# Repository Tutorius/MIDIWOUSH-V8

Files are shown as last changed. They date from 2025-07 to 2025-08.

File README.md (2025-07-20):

# MIDIWOUSH-V8
USB-MIDI-CV-Interface with 8 outputs

All Files for the USB-MIDI-CV-Interface with 8 Outputs

a.) Software & Hardware
Files for ARDUINO IDE. Used Hardware ESP32-S3-WROOM (AliExpress), TCA9548A, GY-MCP4728, 1,30"" IIC Display (all AliExpress)
4 push-buttons (AliExpress)

b.) PCB
KiCAD-Files

To Do:

c.) PCB-Production
PCBWay-Link to project

e.) 3D-files
Files for frontplate, mounting-things, casing for use out of modular System

More Info about use and problems:

At the time i did not find a way to alter the "Midi-Name" (Its something like "ESP32S3_DEV MIDI 1"). Would be nice if it can be named "MIDIWOUSH-V8". Will try to get a solution for this.

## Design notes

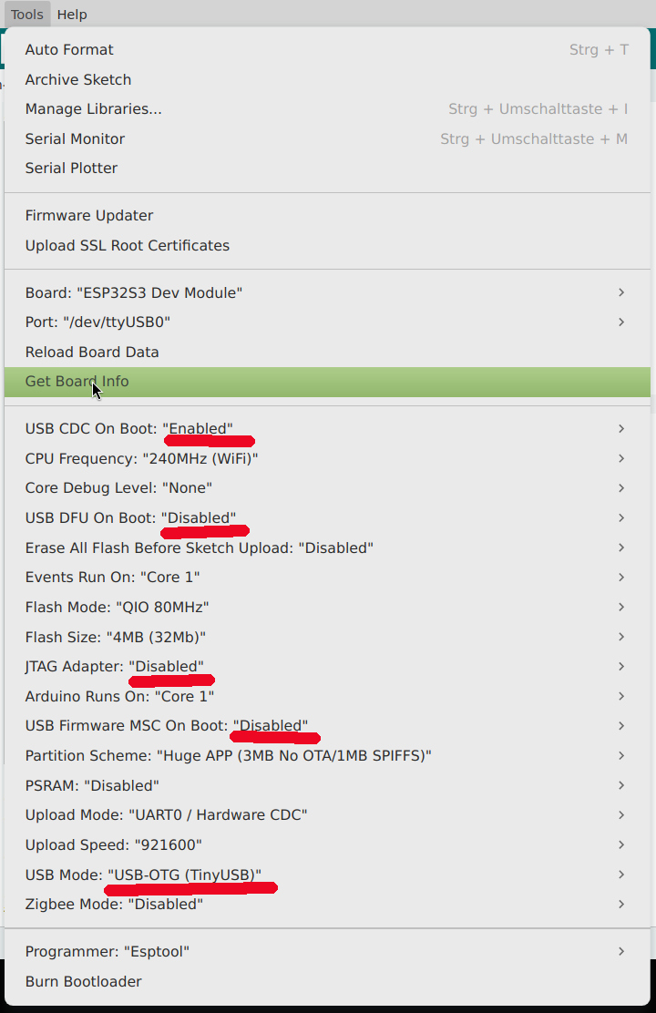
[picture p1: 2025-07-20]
Bildschirmfoto zu 2025-07-20 22-23-47.jpg

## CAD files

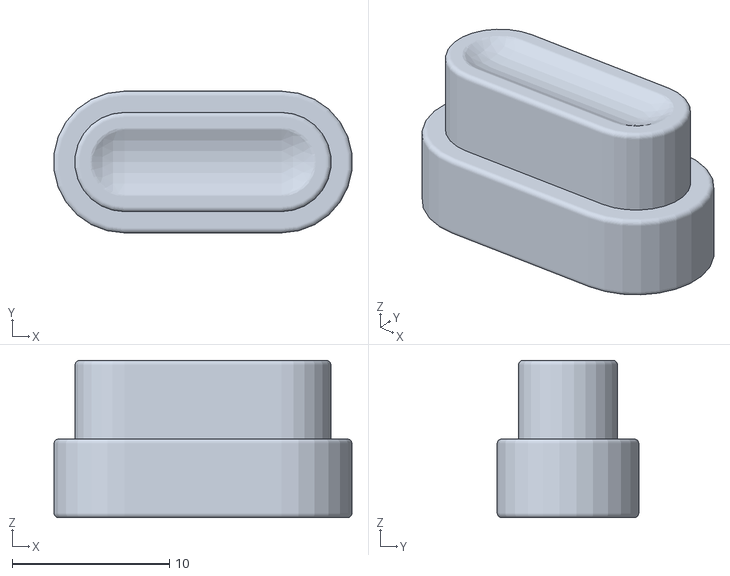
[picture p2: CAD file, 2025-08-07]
Frontplatte2-20250717-Knopf5mm.stl
18.9 x 9.00 x 10.0

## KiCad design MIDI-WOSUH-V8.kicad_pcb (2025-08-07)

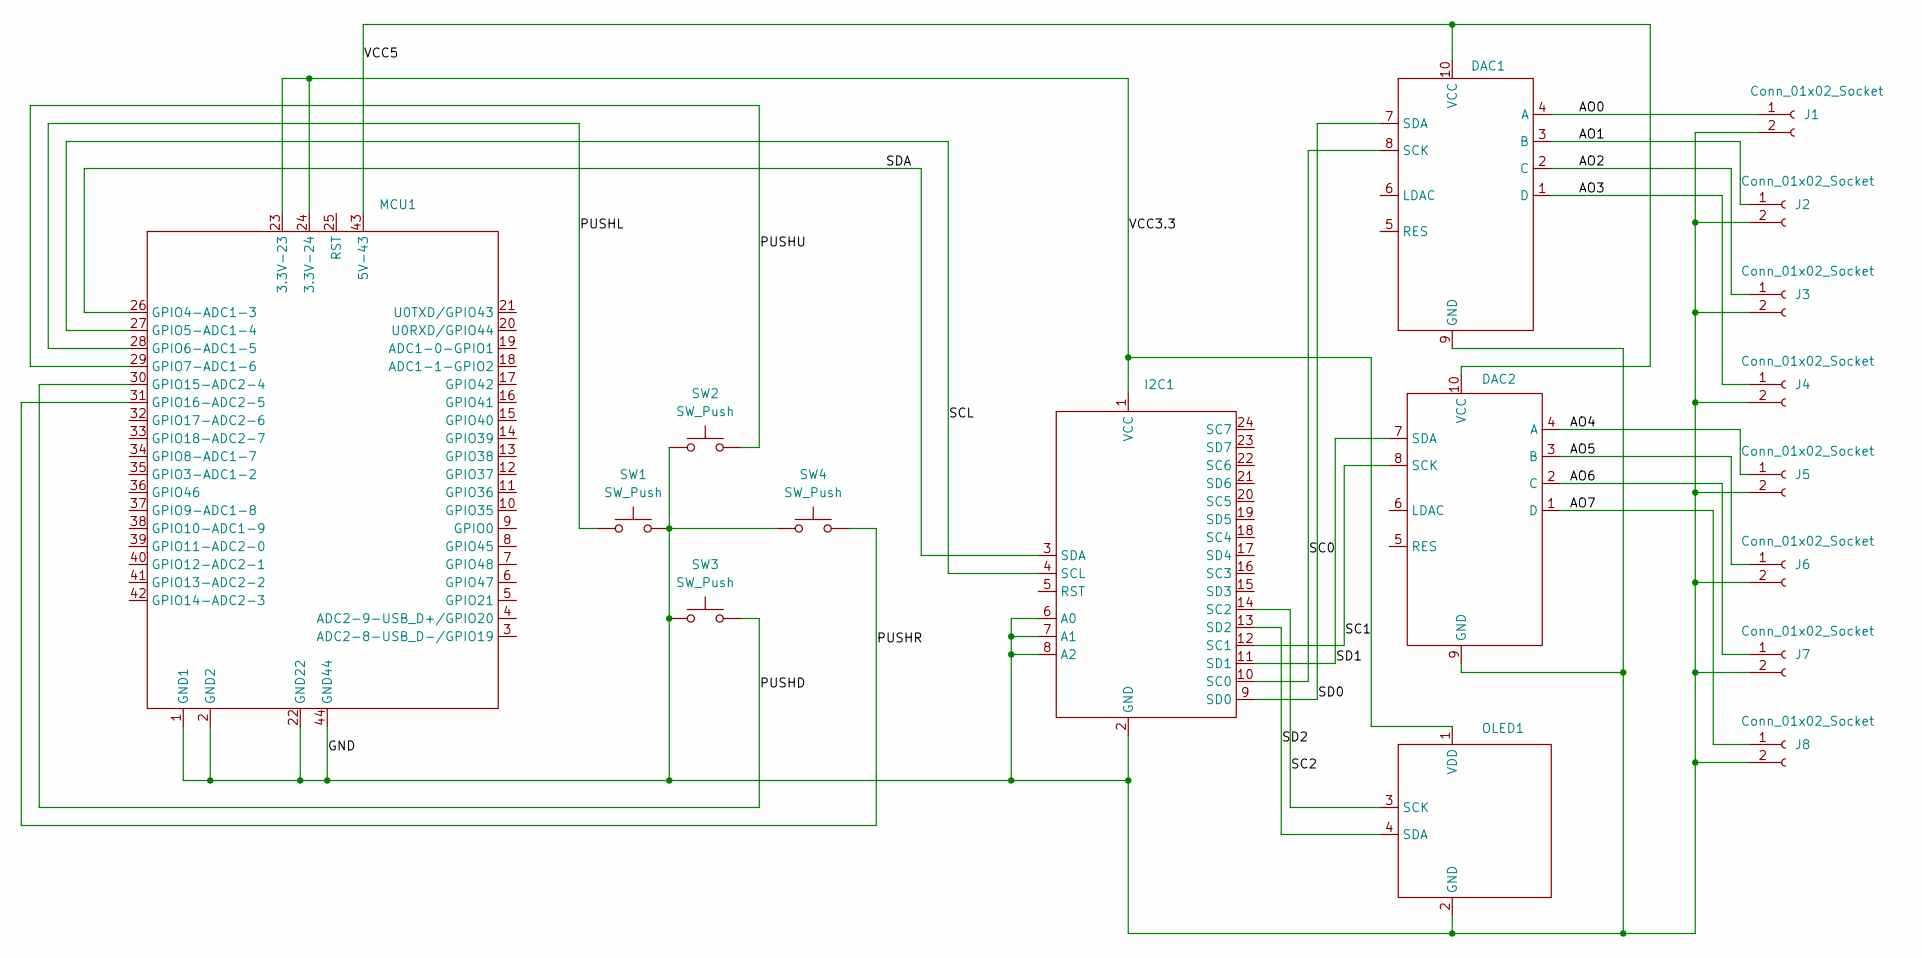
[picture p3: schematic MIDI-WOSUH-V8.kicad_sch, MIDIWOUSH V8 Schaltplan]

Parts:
DAC1, DAC2: MCP4728
I2C1: TCA9548A
J1, J2, J3, J4, J5, J6, J7, J8: Conn_01x02_Socket; PinSocket_1x02_P2.54mm_Vertical
MCU1: ESP32-S3-DevKitC-1
OLED1: OLED
SW1, SW2, SW3, SW4: SW_Push; SWITCH1

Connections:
/AO0: DAC1.4 (A), J1.1
/AO1: DAC1.3 (B), J2.1
/AO2: DAC1.2 (C), J3.1
/AO3: DAC1.1 (D), J4.1
/AO4: DAC2.4 (A), J5.1
/AO5: DAC2.3 (B), J6.1
/AO6: DAC2.2 (C), J7.1
/AO7: DAC2.1 (D), J8.1
/GND: DAC1.9 (GND), DAC2.9 (GND), I2C1.2 (GND), I2C1.6 (A0), I2C1.7 (A1), I2C1.8 (A2), J1.2, J2.2, J3.2, J4.2, J5.2, J6.2, J7.2, J8.2, MCU1.1 (GND1), MCU1.2 (GND2), MCU1.22 (GND22), MCU1.44 (GND44), OLED1.2 (GND), SW1.2, SW2.1, SW3.1, SW4.1
/PUSHD: MCU1.30 (GPIO15-ADC2-4), SW3.2
/PUSHL: MCU1.28 (GPIO6-ADC1-5), SW1.1
/PUSHR: MCU1.31 (GPIO16-ADC2-5), SW4.2
/PUSHU: MCU1.29 (GPIO7-ADC1-6), SW2.2
/SC0: DAC1.8 (SCK), I2C1.10 (SC0)
/SC1: DAC2.8 (SCK), I2C1.12 (SC1)
/SC2: I2C1.14 (SC2), OLED1.3 (SCK)
/SCL: I2C1.4 (SCL), MCU1.27 (GPIO5-ADC1-4)
/SD0: DAC1.7 (SDA), I2C1.9 (SD0)
/SD1: DAC2.7 (SDA), I2C1.11 (SD1)
/SD2: I2C1.13 (SD2), OLED1.4 (SDA)
/SDA: I2C1.3 (SDA), MCU1.26 (GPIO4-ADC1-3)
/VCC3.3: I2C1.1 (VCC), MCU1.23 (3.3V-23), MCU1.24 (3.3V-24), OLED1.1 (VDD)
/VCC5: DAC1.10 (VCC), DAC2.10 (VCC), MCU1.43 (5V-43)

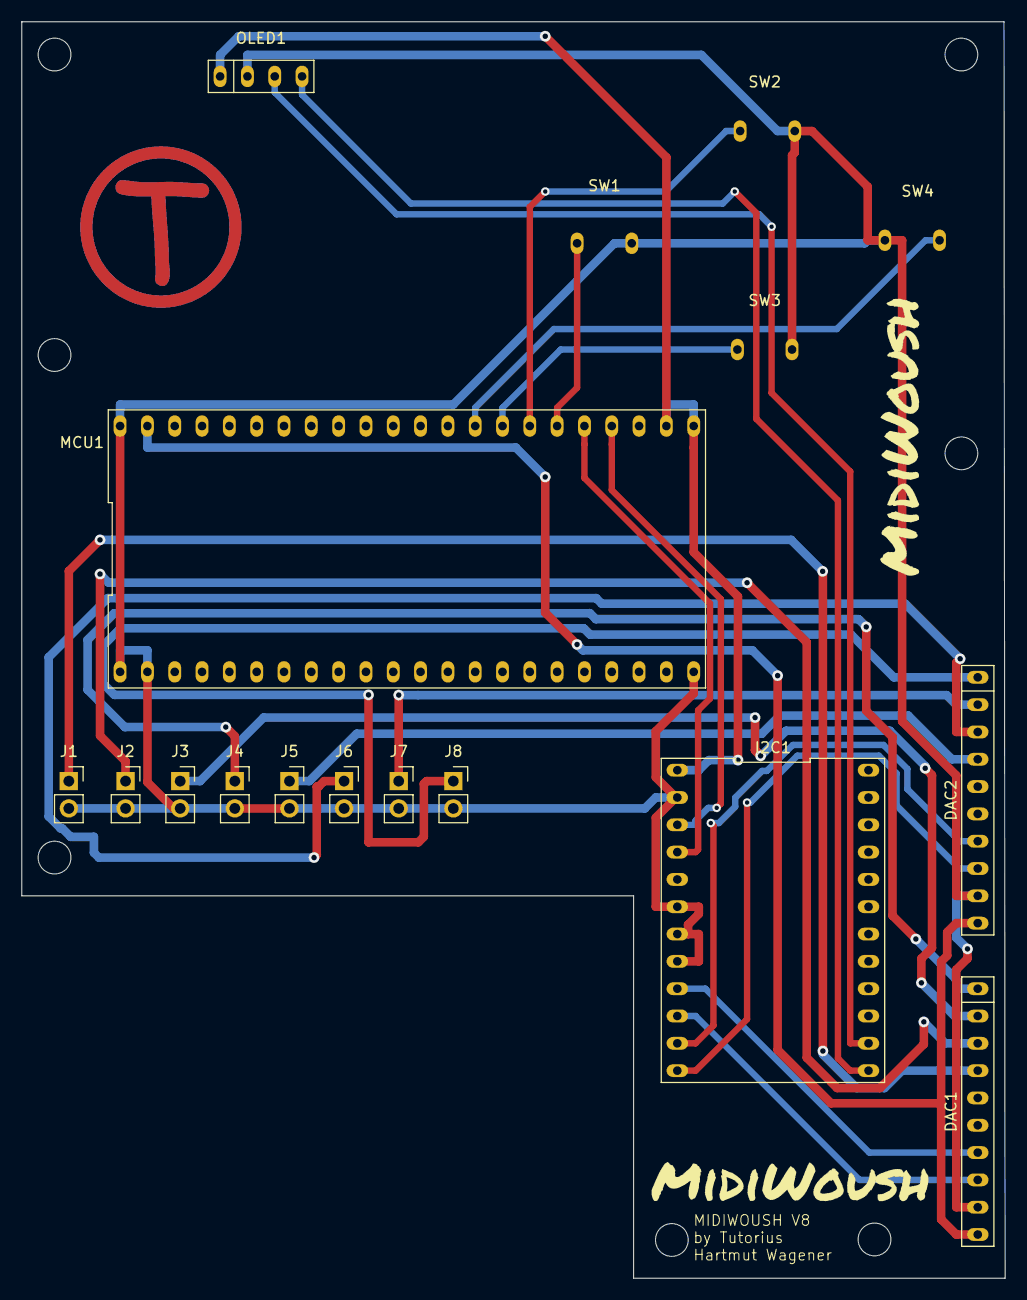
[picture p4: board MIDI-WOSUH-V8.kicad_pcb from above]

Board: 2 copper layers, 91.4 x 116.8 mm, 17 parts (0 on the bottom side), 23 nets.

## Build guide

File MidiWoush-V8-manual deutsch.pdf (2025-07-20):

V8

8-kanal MIDI-CV-Gerät mit USB-MIDI-Schnittstelle und OLED-Display

MidiWoush V8 ist ein Gerät, welches einen oder mehrere Synthesizer mit bis zu acht unabhängigen Spannungen steuern kann. Jede dieser Spannung kann auf einen beliebigen Controller und Midi-Kanal gelegt werden. Die Minimum- und Maximum-Werte können per Prozent-Wert eingegrenzt werden. Die Ausgabe kann durch Vertauschen des Minimum und Maximum-Wertes invertiert werden.
Für Informations-Anzeige und Bedienung ist das Gerät mit einem 1,3-Zoll OLED-Display ausgestattet. Während des Startvorgangs kann dieser auf dem Display verfolgt werden.

Bild 1 : Nach dem Einschalten

Wenn das System gestartet ist wird der Standard-Bildschirm angezeigt. Hier sieht man auch die Funktionen, die linke und rechte Taste durch langes drücken auslösen.

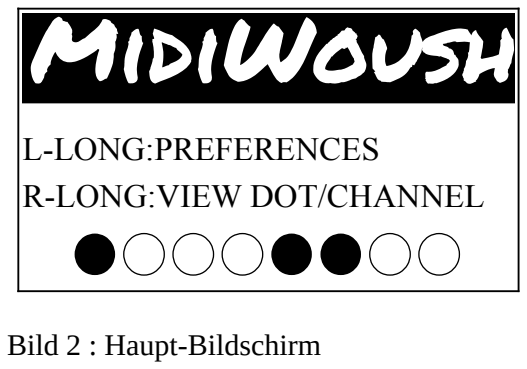
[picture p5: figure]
Bild 2 : Haupt-Bildschirm; L-LONG:PREFERENCES R-LONG:VIEW DOT/CHANNEL

Die acht Kreise zeigen die Port-Aktivität. Sind Kreise ausgefüllt, so wird auf diesem Port die Spannung geändert.

Um zur Kanal-Ansicht zu wechseln drückt man die rechte Taste für ca. eine halbe Sekunde.

INIT UNIT
MCP1
MCP2
RGB-LED

Bild 3 : Kanal-Anzeige

Jeder Kanal wird durch einen Balken angezeigt, am unteren Rand liegt 0 Volt, am oberen Rand +5 Volt.

Einstellungen ändern

Durch Drücken der linken Taste für ca. eine halbe Sekunde gelangt man ins Einstellung-Menü. Ist das Einstellungs-Menü aktiv werden keine Midi-Befehle verarbeitet, Ausgangs-Spannungen werden nicht verändert. Beendet man die Einstellung, so arbeitet MidiWoush V8 weiter wie gewünscht mit geänderten Parametern.

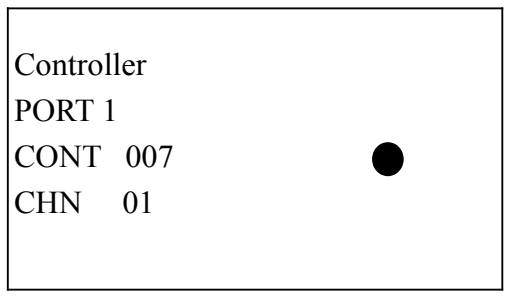
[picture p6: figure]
Controller PORT 1 CONT 007 CHN 01

Bild 4 : Einstellungs-Menü 1. Seite

Hier kann man Änderungen für alle acht Ports vornehmen. Mit dem rechten Knopf gelangt man zum nächsten Port, mit der linken Taste zum vorherigen Port. Ist man auf Port 1, so gelangt man durch die Linke Taste auf Port 8, auf Port 8 gelangt man durch die rechte Taste zu Port 1.

Der gefüllte Kreis zeigt welcher Wert durch die Hoch bzw. Runter-Taste geändert wird. Kurze Tastendrücke mit einer Pause erhöhen bzw. erniedrigen den Wert. Drückt man die Hoch oder Runter-Taste schnell hintereinander, so wird der Controller um 10 Werte erhöht oder erniedrigt, beim Midi-Kanal springt man um drei Werte.

Drückt man die Runter-Taste ca. eine halbe Sekunde, so wird der gefüllte Kreis auf die Zeile für den Midi-Kanal geschoben. Ein langer Druck auf die Hoch-Taste verschiebt diesen Kreis auf die Controller-Zeile.

Zu jeder Zeit kann man mit der linken und rechten-Taste zwischen den Ports wechseln, um schnell Parameter anpassen zu können.

Mehrfach-Belegungen Controller/Midi-Kanal

Wenn einer oder mehrere Ports die selbe Controller/Kanal-Kombination nutzen wird der Bildschirm invertiert angezeigt. Dies warnt sie, aber es funktioniert. Es ist nur keine üblicherweise gewünschte Konfiguration.

Lernen-Modus

Wenn Sie unsicher sind, welchen Controller ihre Hardware oder ihre Midi-Spur nutzt, können Sie den Lernen-Modus nutzen. Um in dden lernen-Modus zu gelangen drückt man die rechte Taste für

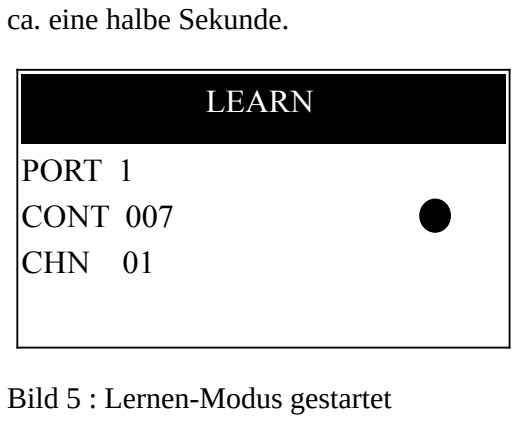
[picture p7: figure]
ca. eine halbe Sekunde.; Bild 5 : Lernen-Modus gestartet; LEARN; PORT 1 CONT 007 CHN 01

Der Text „LEARN“ wird invertiert am oberen Bildschirmrand angezeigt. Nun kann man an der Hardware den passenden Knopf bewegen oder die gewünschte Spur abspielen. Der korrekte Midi-Kanal der Hardware oder Software muss mit MidiWoush verbunden sein.

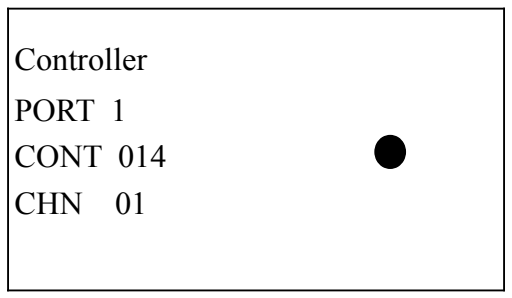
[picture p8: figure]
Controller PORT 1 CONT 014 CHN 01

Bild 6 : Nach dem Lernen

MidiWoush V8 lauscht auf dem Midi-Kanal und ändert den Kanal auf den, auf dem etwas gesendet wird. Wenn das Lernen nicht klappt oder man das unbeabsichtigt gestartet hat kann man mit der linken oder rechten Taste den Lern-Modus beenden.

Drückt man in diesem Edit-Bildschirm die linke Taste für ca. eine halbe Sekunde gelangt man zum MiniMax-Menü. Die Werte für Minimum und Maximum können durch die Hoch- und Runter-Taste geändert werden, der gefüllte Kreis kann auch hier durch langes Drücken der Hoch- und Runtertaste bewegt werden.

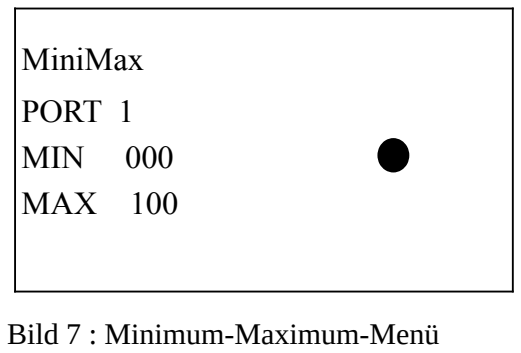
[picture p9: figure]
Bild 7 : Minimum-Maximum-Menü; MiniMax PORT 1 MIN 000 MAX 100

Ein Druck von ca. einer halben Sekunde auf den rechten Knopf vertauscht den Minimum- mit dem Maximum-Wert. Wenn das Minimum größer als das Maximum ist wird der Bildschirm invertiert angezeigt. In diesem Falle wird der Spannungswert invertiert zum Midi-Eingang ausgegeben.

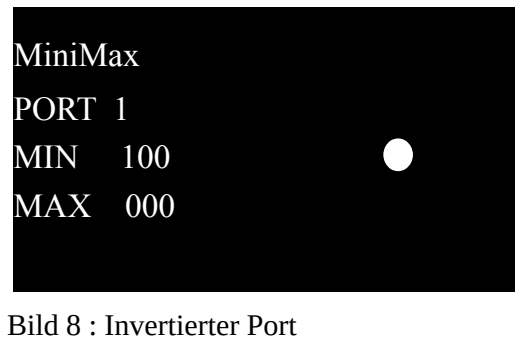
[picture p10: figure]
Bild 8 : Invertierter Port; MiniMax PORT 1 MIN 100 MAX 000

Durch Drücken der linken Taste für ca. eine halbe Sekunde werden die Einstellungen verlassen. Es wird wieder der Standard-Bildschirm angezeigt, die Midi-Kommandos werden verarbeitet,

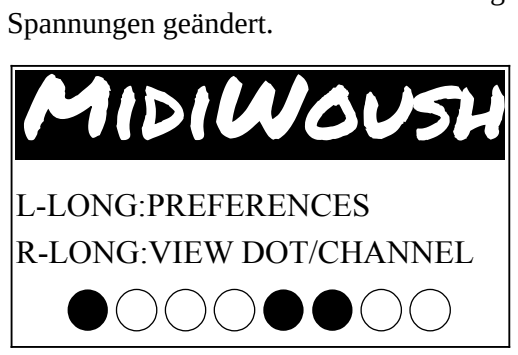
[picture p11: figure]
Spannungen geändert.; L-LONG:PREFERENCES R-LONG:VIEW DOT/CHANNEL

Bild 9 : Standard-Bildschirm wird wieder angezeigt

Werte und Neustart

Alle Änderungen in den Einstellungen werden sofort im nichtflüchtigen Speicher abgelegt. Nach einem Neustart nutzt MidiWoush die Werte, die sie gewählt haben.

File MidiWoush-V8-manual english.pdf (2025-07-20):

V8

8 channel MIDI-CV-Interface with USB-MIDI-Interface and OLED-Display

MidiWoush V8 is an interface to control one ore more synthesizers with up to eight independent voltages. Each voltage can be set to an individual controller and midi-channel. The minimum and maximum-voltages can be set by an percent-value. The output can be inverted (maximum and minimum-value swapped).

For information and settings the device is equipped with an 1,3“-OLED-display. At startup the hardware is initialised, this is logged on the OLED-display.

Image 1 : Startup-Log

After the startup is finished, the display shows the standard-screen, showing the two long pressable buttons and what functions they start.

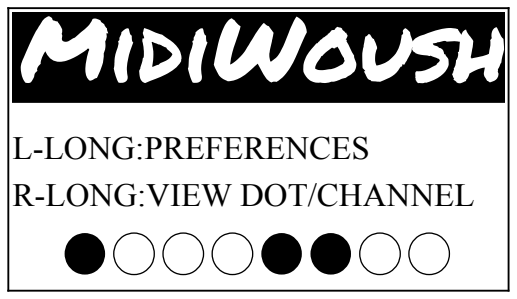
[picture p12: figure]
L-LONG:PREFERENCES R-LONG:VIEW DOT/CHANNEL

Image 2 : Main-Screen

The eight bullets show the active ports of MidiWoush V8 as filled bullets. On these ports the output-voltage changes.

By pressing the Right-Button for minimum half a second you switch the display to channel-view.

INIT UNIT
MCP1
MCP2
RGB-LED

Image 3 : Channel-View

Each channel is shown as a bar, showing the voltage, minimum is 0V at bottom, maximum 5V on top.

Editing the settings

By pressing the left button for a minimum of half a second the system gets to Edit-mode. In this mode, no midi-commands are taken, no voltages are changed. After leaving the edit-mode the system is available as CV-interface again, with the changed settings.

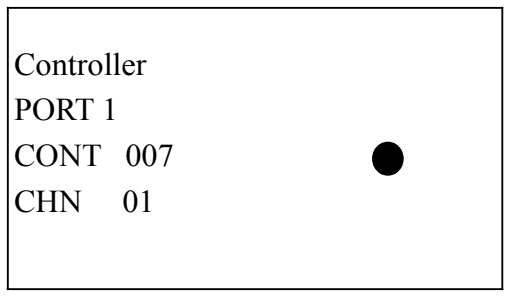
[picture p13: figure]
Controller PORT 1 CONT 007 CHN 01

Image 4 : Settings-Menu 1. Page

You can change the port (1 to 8) by pressing the right button to increment, left button to decrement. Increment at port 8 will go to port 1, decrement at port 1 will go to port 8.

The Bullet shows what value is altered by the up- and down-button. Short clicks with a normal pause increment the value by up-button, decrement by down-button. By pressing up-button multiple with short pause you increment the value by 10 for Controller-value, by 3 for Midi-channel-value. Same is for the down-button, going in 10-steps or 3-steps.

Pressing the down-button long for about half a second the bullet moves to Midi-line and you can edit the midi-channel. Pressing the up-button for about half a second moves the bullet to the Controller-line.

You can change the ports at every time with left and right button, the bullet stays as it is, so you can edit the values for each port.

Multiple Controller/Channels

When one or more of the other ports use the same controller and midi-channel, the screen is inverted to warn you. It works, you may use one output bound to the same channel and controller, but its not usually wanted.

Learn-mode

If you are unsure what controller your track uses, you can use learn-mode. To start the learn-mode for the actual port and midi-channel, you need to press the right-button for about half a second.

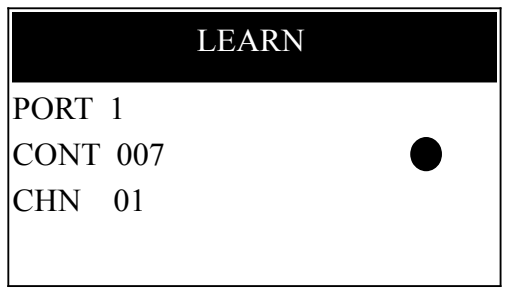
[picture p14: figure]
LEARN; PORT 1 CONT 007 CHN 01

Image 5 : Started Learn-Mode

A inverted „Learn“-text is shown on top of the screen. You can now start to turn the knob or start playback. The track or hardware needs to be connected to a midi-port of the MidiWoush-interface.

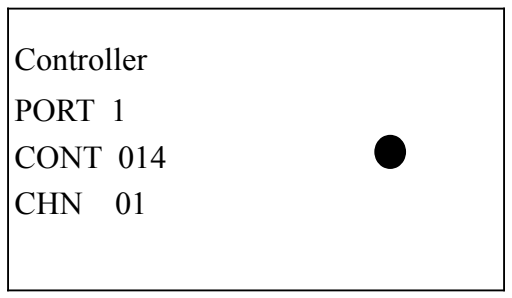
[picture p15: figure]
Controller PORT 1 CONT 014 CHN 01

Image 6 : After learning the controller

MidiWoush V8 listens on the midi-channel and changes the Controller to the one that was send by your hardware. If learn does not work or you have started it unintentionally, a press of the right or left button ends the learn-mode.

In normal edit-view you can press the left button for minimum of half a second. The system shows the MiniMax-view. Here you can changes the values of minimum and maximum with the up and down-buttons. Long presses of up and down-button move the bullet so you can choose if you want

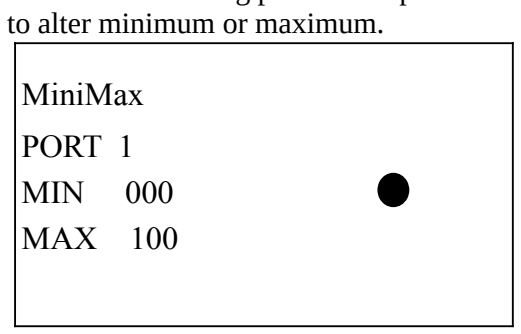
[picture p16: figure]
to alter minimum or maximum.; MiniMax PORT 1 MIN 000 MAX 100

Image 7 : Minimum-Maximum-View

A long press of right button swaps the minimum and maximum-values. The screen is inverted if minimum is higher than maximum. This means that the output acts inverted to the midi-value.

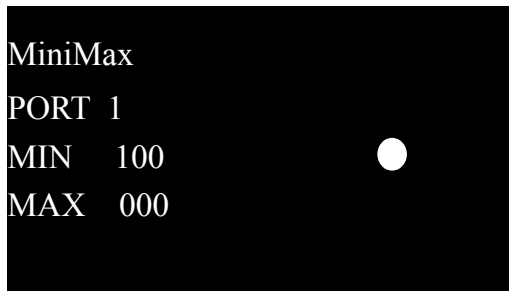
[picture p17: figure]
MiniMax PORT 1 MIN 100 MAX 000

Image 8 : Inverted Port

By pressing the Left-Button for about half a second you leave the Edit-mode. System shows the standard-screen and reacts to midi-commands again, altering the voltage as you want.

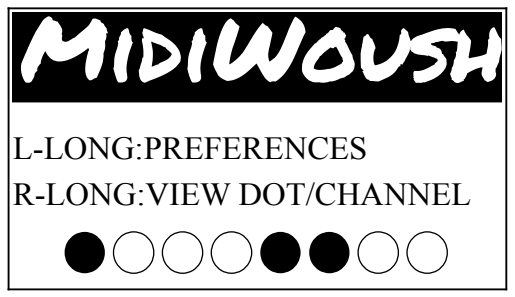
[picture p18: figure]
L-LONG:PREFERENCES R-LONG:VIEW DOT/CHANNEL

Image 9 : Normal-Screen again

Values and Restart

Each change to parameters is directly saved to non-volatile memory. After a restart MidiWoush will work with the parameters that were set before.

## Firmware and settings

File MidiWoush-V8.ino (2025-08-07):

/* ---------------------------------------
   | Changes Hartmut Wagener 20.07.2025  |
   |                                     |
   | changed channel-view to use less    |
   | processor-time                      |
   | changed Learn-mode to only learn    |
   | the controller, midi-channel        |
   | needs to be set correctly before    |
   |                                     |
   |                                     |
   | MIDIWOUSH VoltoMax 8                |
   |                                     |
   | Software for Midi-Controller        |
   | USB-MIDI, 8 different Voltage-      |
   | Channels, can be configured each    |
   | for own Midi-Channel and Controller |
   |                                     |
   | Special-controller for velocity:    |
   | When choosing controller 3 for a    |                                    |
   | midi-channel, a played note instead |                                    |
   | a controller is read and velocity   |
   | is taken for voltage-out            |
   |                                     |
   | Microcontroller: ESP32-S3           |
   | DISPLAY: OLED SH1106 128x64 1,4"    |
   | I2C-Switch: TCA9548A                |
   | 2 X DAC: MCP4728                    |
   | 4 X PUSH-BUTTONS                    |
   |                                     |
   | USB-MIDI BY ADAFRUIT TINY-USB       |
   |                                     |
   | COPYRIGHT HARTMUT WAGENER           |
   | TUTORIUS                            |
   ---------------------------------------
*/
// #define SER 1
// #define SER_DEBUG 1

// #define LED17 1

// Inlcude Servo,SPI,Wire,Display,DAC,MIDIUSB,EEPROM
#include <Arduino.h>
#include <Preferences.h>
#include <Adafruit_TinyUSB.h>
#include <MIDI.h>

#include <SPI.h>
#include <Wire.h>
#include <Adafruit_GFX.h>
#include <Adafruit_SH110X.h>
#include <Adafruit_MCP4728.h>

#include "graphics.h"

#define FRQ400KHZ 1
//#define FRQ1MHZ 1

// Voltage-Difference to lower DAC-interface-time
#define VOLTDIF 1
#define MILLIPLUS 10

// Use Tiny-USB
#define TINYUSB 1

// Position of Activity-Circles
#define YACT 55
#define RACT 5
#define XACT 15
#define X1ACT 6

// Keypress-times
#define EXITPRESS 2000
#define LONGPRESS 500
#define REPEATPRESS 100
#define DEZIPRESS 150
#define PRELLO 50

// Display-Definitions
#define OLED_RESET -1
#define SCREEN_WIDTH 128  // OLED display width, in pixels
#define SCREEN_HEIGHT 64  // OLED display height, in pixels

// Keyboard-Ports
#define KEYLEFT 6
#define KEYUP 7
#define KEYDOWN 15
#define KEYRIGHT 16

// Internal Key-Numbers
#define KeyLeft 1
#define KeyUp 2
#define KeyDown 3
#define KeyRight 4

// Port für RGB-LED
#define RGBLED 48

// RGB-LED-Helligkeit Blink
#define RGBLEDHELL 128

// Maximum channels
#define MAXCHANNELS 8

// Preferences
Preferences preferences;

// USB MIDI object
#ifdef TINYUSB
  Adafruit_USBD_MIDI usb_midi;

  // Create a new instance of the Arduino MIDI Library,
  // and attach usb_midi as the transport.
  MIDI_CREATE_INSTANCE(Adafruit_USBD_MIDI, usb_midi, MIDI);
#endif

#define FZEIL 28

// Display
Adafruit_SH1106G display = Adafruit_SH1106G(SCREEN_WIDTH, SCREEN_HEIGHT, &Wire, OLED_RESET);

// DAC
Adafruit_MCP4728 mcp1;
Adafruit_MCP4728 mcp2;

// Struct for storage of midi-events
typedef struct midicontrol
{
  uint32_t timestamp;
  uint8_t mode; // 0 : leer ; 1 : Controller ; 2 : Note
  uint8_t channel;
  uint8_t val1;
  uint8_t val2;
  int16_t previous;
  int16_t next;
} MIDICONTROL;

MIDICONTROL midibuffer[100];
int16_t first,last;
uint8_t midienable;

// Global variables
// Save old keypresses
uint8_t oldKey[4];
//Key-Ports
uint8_t keyPort[4] = { KEYLEFT, KEYUP, KEYDOWN, KEYRIGHT };

//Which keys can take Longpresses
uint8_t longMask[4] = { true, true, true, true };
//Which Keys can take Repeat-Presses
uint8_t repeatMask[4] = { false, false, false, false };
//Which keys can take Exit-Presses
uint8_t exitMask[4] = { false, false, false, false };
//Which keys can take Dezi-fastklick
uint8_t deziMask[4] = { false, true, true, false };

uint8_t ready;
uint8_t refresh;
uint32_t timer, diffTime;
uint32_t deziTimer;

uint32_t rgbtimer;

uint8_t i, j;

int8_t actPort, oldPort;

//Actual Midi-Config
uint8_t midiController[MAXCHANNELS];
uint8_t midiChannel[MAXCHANNELS];
uint8_t midiMin[MAXCHANNELS];
uint8_t midiMax[MAXCHANNELS];
uint8_t midiInvert[MAXCHANNELS];

// Voltages
uint16_t voltage[8];
uint16_t oldvoltage[8];

// Normal routing of channels to plug-numbers
uint8_t voltnr[8] = { 0, 1, 2, 3, 4, 5, 6, 7 };

// Changed routing when soldering was wrong :) Change as needed and uncomment
// uint8_t voltnr[8] = { 3, 2, 1, 0, 7, 6, 5, 4 };

// Activity-"LEDs"
uint16_t activity[8];

uint32_t milliSave, milliSave2, milliSave3;
uint8_t milliflag;

//Input-Mode
int8_t inputMode;

uint8_t flag;
char s[80];

int rgbpos, rgbakt;
float rgbval;
float rgbhell;

// Handle for Controllerchange-Events
void handleControllerChange(byte channel, byte controller, byte value)
{
  uint8_t i;
  if(!midienable) return;
  cli();
  i=0;
  
  while((midibuffer[i].mode!=0)&&(i<100))
  {
    i++;
  }
  if(i<100)
  {
    midibuffer[i].timestamp=millis();
    midibuffer[i].channel=channel;
    midibuffer[i].mode=1;
    midibuffer[i].val1=controller;
    midibuffer[i].val2=value;
    if (first==-1)
    {
      first=i; last=i;
      midibuffer[i].next=-1;
      midibuffer[i].previous=-1;
    }
    else
    {
      midibuffer[i].previous=last;
      midibuffer[last].next=i;
      last=i;
    }
  }
  sei();
}

// Handle for NotoOn-Events
void handleNoteOn(byte channel, byte pitch, byte velocity)
{
  uint8_t i;
  if(!midienable) return;
  cli();
  i=0;
  while((midibuffer[i].mode!=0)&&(i<100))
  {
    i++;
  }
  if(i<100)
  {
    midibuffer[i].timestamp=millis();
    midibuffer[i].channel=channel;
    midibuffer[i].mode=2;
    midibuffer[i].val1=pitch;
    midibuffer[i].val2=velocity;
    if (first==-1)
    {
      first=i; last=i;
      midibuffer[i].next=-1;
      midibuffer[i].previous=-1;
    }
    else
    {
      midibuffer[i].previous=last;
      midibuffer[last].next=i;
      last=i;
    }
  }
  sei();
}

int16_t getFirst()
{
  return(first);
}

int16_t getLast()
{
  return(last);
}

int16_t getNextFree()
{
  int16_t i,j;
  j=-1;
  for(i=0;i<100;i++)
  {
    if(midibuffer[i].mode==0)
    {
      j=i;
      break;
    }
  }
  return(j);
}

int16_t delFirst()
{
  if(first==-1)
    return(-1);
  else
  {
    if(midibuffer[first].mode==0)
    {
      first=-1;
      return(-1);
    }
    else
    {
      midibuffer[first].mode=0;
      first=midibuffer[first].next;
      if(first>=0)
        midibuffer[first].previous=-1;
    }
  }
  return(first);
}

// Handle for NoteOff-Events (not needed now)
void handleNoteOff(byte channel, byte pitch, byte velocity)
{
  if(!midienable) return;

}

// Select I2C-Bus 0...7
void selectBus(uint8_t bus)
{
  Wire.beginTransmission(0x70);  // TCA9548A address is 0x70
  Wire.write(1 << bus);          // send byte to select bus
  Wire.endTransmission();
}

/* CalcVOLT(float val,uint8_t min,uint8_t max)
  Calculates the Voltage for DAC
  val: 0-127, min, max 0-100
*/
uint16_t CalcVOLT(float val, uint8_t min, uint8_t max)
{
  float minf, maxf, diff;
  float p1, p2;
  float px;
  minf = 0.0;
  maxf = 4095.0;
  diff = maxf - minf;
  p1 = (float)min;
  p2 = (float)max;
  p1 = p1 * 0.01;
  p2 = p2 * 0.01;
  px = val * diff * (p2 - p1);
  if (p2 > p1)
    px = px + minf;
  else
    px = maxf + px;
  return ((uint16_t)px);
}

/* int8_t scankey(uint8_t keyNr)
    Scans the key number 'keyNr' for normal presses
    and long presses
*/
int8_t scanKey(uint8_t keyNr)
{
  int8_t keyPressed1;
  // Button 'keyNr' pressed?
  keyPressed1 = -1;
  if (!digitalRead(keyPort[keyNr]))
  {
    // Key pressed, newly pressed?
    if (!oldKey[keyNr])
    {
      // Yes, newly pressed
      timer = millis();
      diffTime = 0;
      oldKey[keyNr] = true;
      if ((!longMask[keyNr]) && (!repeatMask[keyNr]) && (!exitMask[keyNr]))
      {
        keyPressed1 = keyNr;
      }
      if (deziMask[keyNr])
      {
        if (millis() - deziTimer <= DEZIPRESS)
        {
          if (millis() - deziTimer >= PRELLO)
          {
            keyPressed1 = keyNr | 0x20;
            deziTimer = millis();
          }
        }
      }
    }
    else
    {
      // No, not newly pressed
      if (longMask[keyNr])
      {
        // Langdruck der Taste abfragen
        if (millis() - timer >= LONGPRESS)
        {
          keyPressed1 = keyNr | 0x40;
        }
      }
      else
      {
        if (repeatMask[keyNr])
        {
          // Repeatdruck der Taste abfragen
          if (millis() - timer >= REPEATPRESS)
          {
            timer = millis();
            keyPressed1 = keyNr;
            oldKey[keyNr] = false;
          }
        }
        else
        {
          // Exitdruck der Tasten abfragen
          if (exitMask[keyNr])
          {
            if (millis() - timer > EXITPRESS)
            {
              keyPressed1 = keyNr | 0x80;
              ready = true;
            }
          }
        }
      }
    }
  }
  else
  {
    // No, pressed before?
    if (oldKey[keyNr])
    {
      if (millis() - timer > PRELLO)
      {
        oldKey[keyNr] = false;
        // Yes, pressed before
        if (deziMask[keyNr])
          deziTimer = millis();
        if (longMask[keyNr])
        {
          if (keyPressed1 < 0)
          {
            if (millis() - timer < LONGPRESS)
            {
              keyPressed1 = keyNr;
            }
            else
            {
              keyPressed1 = keyNr | 0x40;
            }
          }
          timer = millis();
        }
        else
        {
          if (repeatMask[keyNr])
          {
            oldKey[keyNr] = false;
          }
          else
          {
            if (exitMask[keyNr])
            {
              oldKey[keyNr] = false;
            }
            else
            {
              oldKey[keyNr] = false;
            }
          }
        }
      }
      else
      {
        timer = millis();
      }
    }
  }
  return (keyPressed1);
}

/* int scanKeys()
  Scans all Keys for Key-presses
*/
int scanKeys()
{
  int8_t keyPressed;
  uint8_t i;
  keyPressed = -1;
  for (i = 0; i < 4; i++)
  {
    keyPressed = scanKey(i);
    if (keyPressed >= 0) break;
  }
  return (keyPressed);
}

/* refreshDisplay(int mode)
  Refreshes the display
*/
void refreshDisplay(int mode)
{
  uint8_t i, flag, posy;
  selectBus(2);
  display.clearDisplay();
  flag = false;
  switch (mode)
  {
    case 0:  // Display: Controller and Midi-Channel
      flag = false;
      for (i = 0; i < MAXCHANNELS; i++)
      {
        if (i != actPort)
        {
          if ((midiController[actPort] == midiController[i]) && (midiChannel[actPort] == midiChannel[i]))
          {
            flag = true;
          }
        }
      }
      if (flag)
      {
        display.setTextColor(SH110X_BLACK);
        display.fillRect(0, 0, 128, 64, SH110X_WHITE);
      }
      else
      {
        display.setTextColor(SH110X_WHITE);
      }
      display.setCursor(0, 0);
      display.println("Controller");
      sprintf(s, "PORT %d", actPort + 1);
      display.println(s);
      sprintf(s, "CONT %3d", midiController[actPort]);
      for (i = 5; i < strlen(s); i++)
        if (s[i] == ' ') s[i] = '0';
      display.println(s);
      sprintf(s, "CHN  %2d", midiChannel[actPort] + 1);
      for (i = 5; i < strlen(s); i++)
        if (s[i] == ' ') s[i] = '0';
      display.println(s);
      if (inputMode == 0) posy = 38;
      else posy = 54;
      if (!flag)
        display.fillCircle(117, posy, 5, SH110X_WHITE);
      else
        display.fillCircle(117, posy, 5, SH110X_BLACK);
      display.display();
      refresh = false;
      break;
    case 1:  // Display: Min and Max-Values
      flag=(midiMin[actPort]<=midiMax[actPort]);
      if (flag)
      {
        display.setTextColor(SH110X_WHITE);
        display.setCursor(0, 0);
        display.println("MinMax");
        sprintf(s, "PORT %d", actPort + 1);
        display.println(s);
        sprintf(s, "MIN %3d", midiMin[actPort]);
        for (i = 4; i < strlen(s); i++)
          if (s[i] == ' ') s[i] = '0';
        display.println(s);
        sprintf(s, "MAX %3d", midiMax[actPort]);
        for (i = 4; i < strlen(s); i++)
          if (s[i] == ' ') s[i] = '0';
        display.println(s);
        if (inputMode == 0) posy = 22 + 16;
        else posy = 38 + 16;
        display.fillCircle(128 - 11, posy, 5, SH110X_WHITE);
        // display.fillCircle(128 - 11, posy, 5, SH110X_BLACK);
        display.display();
        refresh = false;
      }
      else
      {
        display.setTextColor(SH110X_BLACK);
        display.fillRect(0, 0, 128, 64, SH110X_WHITE);
        display.setCursor(0, 0);
        display.println("MinMax");
        sprintf(s, "PORT %d", actPort + 1);
        display.println(s);
        sprintf(s, "MAX %3d", midiMin[actPort]);
        for (i = 4; i < strlen(s); i++)
          if (s[i] == ' ') s[i] = '0';
        display.println(s);
        sprintf(s, "MIN %3d", midiMax[actPort]);
        for (i = 4; i < strlen(s); i++)
          if (s[i] == ' ') s[i] = '0';
        display.println(s);
        if (inputMode == 0) posy = 22 + 16;
        else posy = 38 + 16;
        display.fillCircle(128 - 11, posy, 5, SH110X_BLACK);
        display.display();
        refresh = false;
      }
      display.setTextColor(SH110X_WHITE);
      break;
  }
}

/* void EditMidi(int mode)
  Edits the actual Midi-Settings
*/
void EditMidi(int mode)
{
  int keyPressed;
  int j;
  uint8_t dummy;
  uint8_t swapflag,learnflag;
  uint8_t learnmode; // mode 0 -> Listen on actual channel; mode 1 -> Listen on all channels

  uint8_t rgbflash; // 0-> rot ; 1-> blau; 2-> grün
  uint8_t rgbanaus;
  uint32_t rgbtimer;
  uint32_t buffertimer;

  rgbtimer=millis();
  swapflag=true;
  learnflag=true;
  learnmode=0;
  rgbflash=0;
  rgbanaus=true;


  
  selectBus(2);
  display.setTextSize(2);
  do
  {
    if (TinyUSBDevice.mounted())
    {
      MIDI.read();
    }

    if (millis()>rgbtimer+500)
    {
      rgbtimer=millis();
      if(rgbanaus)
      {
        switch(mode)
        {
          case 0:
            rgbLedWrite(RGBLED, RGBLEDHELL, 0, 0);
            break;
          case 1:
            rgbLedWrite(RGBLED,0,RGBLEDHELL,0);
            break;
        }
        rgbanaus=false;
      }
      else
      {
        rgbLedWrite(RGBLED, 0, 0, 0);
        rgbanaus=true;
      }
    }
    if (refresh)
    {
      refreshDisplay(mode);
    }
    keyPressed = scanKeys();
    if(keyPressed==-1)
    {
      swapflag=true;
      learnflag=true;
    }
    switch (keyPressed)
    {
      // Key Left Short
      case 0:
        if (actPort > 0) actPort--;
        else actPort = MAXCHANNELS - 1;
        refresh = true;
        break;
      // Key Up Short
      case 1:
        switch (mode)
        { 
          case 0:
            // Edit Conroller/Channel
            switch (inputMode)
            {
              case 0:
                if (midiController[actPort] < 150) midiController[actPort]++;
                else midiController[actPort] = 0;
                refresh = true;
                break;
              case 1:
                if (midiChannel[actPort] < 15) midiChannel[actPort]++;
                else midiChannel[actPort] = 0;
                refresh = true;
                break;
            }
            break;
          case 1:
            // Edit MiniMax
            switch (inputMode)
            {
              case 0:
                if (midiMin[actPort] < 100) midiMin[actPort]++;
                else midiMin[actPort] = 0;
                refresh = true;
                break;
              case 1:
                if (midiMax[actPort] < 100) midiMax[actPort]++;
                else midiMax[actPort] = 0;
                refresh = true;
                break;
            }
            break;
        }
        break;
      // Key Down Short
      case 2:
        switch (mode)
        {
          case 0:
            // Edit Controller/Channel
            switch (inputMode)
            {
              case 0:
                if (midiController[actPort] > 0) midiController[actPort]--;
                else midiController[actPort] = 150;
                refresh = true;
                break;
              case 1:
                if (midiChannel[actPort] > 0) midiChannel[actPort]--;
                else midiChannel[actPort] = 15;
                refresh = true;
                break;
            }
            break;
          case 1:
            // Edit MiniMax
            switch (inputMode)
            {
              case 0:
                if (midiMin[actPort] > 0) midiMin[actPort]--;
                else midiMin[actPort] = 100;
                refresh = true;
                break;
              case 1:
                if (midiMax[actPort] > 0) midiMax[actPort]--;
                else midiMax[actPort] = 100;
                refresh = true;
                break;
            }
            break;
        }
        break;
      // Key Right Short
      case 3:
        if (actPort < MAXCHANNELS - 1) actPort++;
        else actPort = 0;
        refresh = true;
        break;
      // Key up long
      case 0x41:
        // Switch to InputMode Line1
        inputMode = 0;
        refresh = true;
        break;
      // Key down long
      case 0x42:
        // Switch to InputMode Line2
        inputMode = 1;
        refresh = true;
        break;
      // Key Left Long
      case 0x40:
        // Exit Edit
        ready = true;
        break;
      // Key Right Long - Learn Midi - Swap MiniMax
      case 0x43:
        switch(mode)
        {
          case 0:
            // Edit Controller/Channel
            // Learn Midi
            // Delete buffered Midi-events
            while(!digitalRead(KEYRIGHT));
            if(learnflag)
            {
              first=-1;
              last=-1;
              for(i=0;i<100;i++) midibuffer[i].mode=0;
              midienable=true;
              rgbflash=1;
              learnflag=false;
              selectBus(2);
              display.setCursor(0, 0);
              display.fillRect(0, 0, 128, 16, SH110X_WHITE);
              display.setTextColor(SH110X_BLACK);
              display.printf("   LEARN1");
              display.display();
              j = 50000;
              rgbtimer=millis();
              rgbanaus=true;
              rgbLedWrite(RGBLED, 0, 0, RGBLEDHELL);
              // Buffer leeren
              buffertimer=millis();
              // MIDI-Buffer löschen
              learnmode=0;
              // BBB
              flag=true;
              first=-1;
              last=-1;
              for(i=0;i<100;i++)
              {
                midibuffer[i].mode=0;
              }
              do
              {
                if (TinyUSBDevice.mounted())
                {
                  MIDI.read();
                }
                if(millis()>rgbtimer+500)
                {
                  if(rgbanaus)
                  {
                    rgbanaus=false;
                    rgbLedWrite(RGBLED,0,0,0);
                  }
                  else
                  {
                    rgbanaus=true;
                    switch(learnmode)
                    {
                      case 0:
                        rgbLedWrite(RGBLED,0,0,RGBLEDHELL);
                        break;
                      case 1:
                        rgbLedWrite(RGBLED,RGBLEDHELL,RGBLEDHELL,0);
                        break;
                    }
                  }
                  rgbtimer=millis();
                }
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
void loop()
{

}

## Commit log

2025-07-20 Settings of Arduino-IDE for uploading to ESP32-S3
    Vital settings for uploading via Arduino-IDE to ESP32-S3-WROOM (preferably on USB-port (left-upper) ) for Tiny-USB-MIDI
2025-08-07 Add files via upload
    Knob for Module (4 times needed)
    [Frontplatte2-20250717-Knopf5mm.stl]
